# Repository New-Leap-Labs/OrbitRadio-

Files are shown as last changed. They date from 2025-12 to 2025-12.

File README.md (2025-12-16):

# Somaiya OrbitRadio

## APRS/AFSK Transceiver System

**STM32F4-based APRS packet radio system with Bell 202 AFSK modulation for amateur radio communication**

---

## Overview

This project implements a complete APRS (Automatic Packet Reporting System) transceiver using STM32F4 microcontroller with the following capabilities:

- Bell 202 AFSK modulation (1200 Hz mark, 2200 Hz space at 1200 baud)
- AX.25 packet protocol for amateur radio
- DRA818U radio module integration
- 4-bit R-2R DAC for audio generation
- UART packet reception with validation
- IWDG watchdog for system reliability

### Key Features

- Packet-triggered transmission (no auto-beacon)
- Robust input validation (ASCII-only payloads)
- Memory-optimized design (512-byte buffers)
- Watchdog protection against system hangs
- 9600 Hz sample rate audio generation
- Hardware-accelerated DAC output

---

## Hardware Requirements

### Microcontroller
- STM32F446RE Nucleo board (or compatible STM32F4 series)
- Upto 180 MHz system clock
- 512 KB Flash memory
- 128 KB SRAM + 4 KB backup SRAM

### Radio Module
- DRA818U/V UHF/VHF transceiver module
- Currently configured for UHF operation at 435.2480 MHz (default) or 435.2500 MHz (backup)
- Supports VHF operation as well (configurable when required)
- UART control interface at 9600 baud

### DAC Configuration (4-bit R-2R Ladder)

| STM32 Pin | DAC Bit | Resistor Value |
|---|---|---|
| PA6 | MSB (bit 0) | R |
| PA4 | bit 1 | 2R |
| PA1 | bit 2 | 4R |
| PA0 | LSB (bit 3) | 6R |

**R-2R Network:** Use 1kΩ for R, 2kΩ for 2R  
**Output:** Connect DAC output to DRA818 microphone input via 10µF coupling capacitor

### Pin Configuration

- PA10 (USART1 RX): Packet data input at 115200 baud
- PC7 (PTT_UHF): Push-to-talk control for DRA818
- PA5 (LD2): Status LED (toggles on valid packet reception)

---

## Packet Structure

### DataPacket_t Format (260 bytes total)

```c
typedef struct {
    uint8_t command_type;      // 0x01 = Frequency Change, 0x02 = Telemetry
    uint8_t payload_length;    // 1-256 bytes
    uint8_t padding[2];        // Reserved (ignored)
    uint8_t payload[256];      // ASCII text payload
} DataPacket_t;
```

### Valid Command Types

- 0x01 - Frequency change command (currently triggers telemetry)
- 0x02 - Telemetry transmission

### Payload Validation Rules

**Accepted Characters:**
- Printable ASCII: 0x20-0x7E (space through tilde)
- Whitespace: \t (0x09), \n (0x0A), \r (0x0D)

**Rejected Packets:**
- Empty payloads (length = 0)
- Oversized payloads (length > 256)
- Invalid command types (not 0x01 or 0x02)
- Non-ASCII data (binary/control characters)

---

## APRS Packet Format

Generated APRS packets follow AX.25 UI-frame structure:

```
Flag | Dest Addr | Src Addr | Path | Control | PID | Info Field | FCS | Flag
0x7E | VU2CWN-0  | VU3CDI-5 | WIDE1-1,WIDE2-1 | 0x03 | 0xF0 | >Payload... | CRC | 0x7E
```

### Callsign Configuration

Edit the following definitions in `main.c`:

```c
#define SRC_CALL   "VU3CDI"    // Source callsign
#define SRC_SSID   5           // Source SSID
#define DST_CALL   "VU2CWN"    // Destination callsign
#define DST_SSID   0           // Destination SSID
#define PATH1_CALL "WIDE1"     // Digipeater path 1
#define PATH1_SSID 1
#define PATH2_CALL "WIDE2"     // Digipeater path 2
#define PATH2_SSID 1
```

---

## Getting Started

### 1. Clone Repository

```bash
git clone https://github.com/yourusername/OrbitRadio-APRS.git
cd OrbitRadio-APRS
```

### 2. Open in STM32CubeIDE

- Open STM32CubeIDE
- Navigate to File → Open Projects from File System
- Select the project folder
- Build the project (Ctrl+B)

### 3. Configure IWDG Watchdog

- Open `RX_Final.ioc`
- Navigate to Computing → IWDG
- Enable IWDG
- Set Prescaler: 64, Reload: 4095 (timeout approximately 8.2 seconds)
- Save and regenerate code

### 4. Flash to STM32

- Connect STM32 Nucleo via USB
- Click Run (green play button) or press F11

### 5. Hardware Connections

```
STM32 PA10 (RX) ←─── UART TX from sender device
STM32 PC7 (PTT) ───→ DRA818 PTT pin
STM32 DAC Out   ───→ DRA818 MIC (via 10µF capacitor)
DRA818 Audio    ───→ Radio antenna/speaker
```

---

## Usage

### Sending a Packet (Python Example)

```python
import serial
import struct

ser = serial.Serial('COM3', 115200)  # Adjust port

# Create packet
command_type = 0x02  # Telemetry
payload = b"Temperature: 25.3C, Humidity: 60%"
payload_length = len(payload)

# Pack packet (4-byte header + payload)
packet = struct.pack('<BB2s', command_type, payload_length, b'\x00\x00')
packet += payload.ljust(256, b'\x00')  # Pad to 256 bytes

# Send
ser.write(packet)
print(f"Sent {len(packet)} bytes")
ser.close()
```

### Expected System Behavior

1. PTT activates (PC7 goes HIGH)
2. AFSK tones generated via DAC (1200/2200 Hz)
3. Radio transmits APRS packet
4. PTT releases after transmission

### Transmission Time Calculation

```
Time (seconds) = (Packet bytes × 8 bits) / 1200 baud
Example: 75 bytes = (75 × 8) / 1200 = 0.5 seconds
```

---

## AFSK Technical Details

### Bell 202 Standard

- Mark (binary 1): 1200 Hz
- Space (binary 0): 2200 Hz
- Baud rate: 1200 baud
- Sample rate: 9600 Hz (Timer3 interrupt)

### Audio Generation Pipeline

```
AX.25 Encoder → AFSK Modulator → Timer3 ISR → 4-bit DAC → Analog Audio
   (ax25.c)       (afsk.c)      (9600 Hz)    (R-2R)      (DRA818)
```

### Timer3 Configuration

```c
Clock: 84 MHz APB1
Prescaler: 83  → 84MHz / 84 = 1 MHz
Period: 103    → 1MHz / 104 ≈ 9615 Hz ≈ 9600 Hz
```

At 9600 Hz sample rate:
- 1200 Hz tone = 8 samples per cycle
- 2200 Hz tone = 4.36 samples per cycle

---

## Watchdog Protection

### IWDG Configuration

- Timeout: approximately 8.2 seconds
- Prescaler: 64
- Reload value: 4095
- LSI Clock: 32 kHz

### Refresh Points

- Main loop: Every 10ms
- Packet processing start
- During AFSK transmission (multiple points)
- After long delays

**Purpose:** Automatically reset system if hang or crash occurs

---

## Memory Usage

| Resource | Size | Usage |
| --- | --- | --- |
| Flash | 512 KB | Program code and constants |
| **SRAM** | **128 KB** | Runtime data, stack, heap |
| **Backup SRAM** | **4 KB** | Retained data during standby |
| AX.25 Buffer | 512 bytes  | Packet encoding |
| RX Buffer | 260 bytes  | UART reception |
| Process Buffer  | 260 bytes  | Packet processing |
| DAC Masks | 128 bytes  | Precomputed GPIO values |

### Optimizations

- Reduced AX.25 buffer from 4096 to 512 bytes
- Minimized stack usage in string operations
- Precomputed DAC lookup tables

---

## Troubleshooting

### Packets Rejected

**Causes:**
- Invalid command type (must be 0x01 or 0x02)
- Payload contains non-ASCII characters
- Payload length = 0 or > 256
- UART framing errors

**Solution:** Verify packet structure and ensure clean ASCII text

### No Audio Output

**Symptoms:** PTT activates but no tones  
**Causes:**
- R-2R DAC not connected properly
- Wrong GPIO pins
- Timer3 not running

**Solution:** Verify DAC wiring and check Timer3 initialization

### Radio Not Transmitting

**Symptoms:** Audio plays but no RF output  
**Causes:**
- DRA818 not initialized
- Wrong frequency/configuration
- PTT not connected

**Solution:** Check USART6 connection to DRA818 and verify AT commands

### System Hangs or Resets

**Symptoms:** Unexpected resets  
**Causes:**
- Watchdog timeout (hung code)
- Missing HAL_IWDG_Refresh() calls

**Solution:** Increase IWDG timeout or add more refresh points

---

## Project Structure

```
RX_Final/
├── Core/
│   ├── Inc/
│   │   ├── main.h              # Pin definitions, function prototypes
│   │   ├── afsk.h              # AFSK generator declarations
│   │   ├── ax25.h              # AX.25 encoder declarations
│   │   └── stm32f4xx_it.h      # Interrupt handlers
│   └── Src/
│       ├── main.c              # Main application logic
│       ├── afsk.c              # AFSK audio generation
│       ├── ax25.c              # AX.25 packet encoding
│       ├── stm32f4xx_it.c      # ISR implementations
│       └── stm32f4xx_hal_msp.c # HAL initialization
├── Drivers/                     # STM32 HAL drivers
├── RX_Final.ioc                # STM32CubeMX configuration
└── README.md                   # This file
```

---

## Technical References

- [APRS Protocol Specification](http://www.aprs.org/doc/APRS101.PDF)
- [AX.25 Link Access Protocol](https://www.tapr.org/pdf/AX25.2.2.pdf)
- [Bell 202 Standard](https://en.wikipedia.org/wiki/Bell_202_modem)
- [DRA818 Datasheet](http://www.dorji.com/docs/data/DRA818U.pdf)
- [STM32F4 Reference Manual](https://www.st.com/resource/en/reference_manual/dm00031020.pdf)

---

## Authors

**Somaiya OrbitRadio Team**

Callsigns: VU3CDI, VU3LTQ, VU3DNW, VU3DUN, VU2CWN

Project: APRS/AFSK Transceiver for Amateur Radio

---

## Acknowledgments

- STMicroelectronics for STM32Cube HAL
- APRS/AX.25 protocol developers
- DRA818 module creators
- Amateur radio community

---

## Contact

For questions or support:
- Open an issue on GitHub
- Email: nli@somaiya.edu

---

**73 de Somaiya OrbitRadio Team**

*Last updated: December 2025*

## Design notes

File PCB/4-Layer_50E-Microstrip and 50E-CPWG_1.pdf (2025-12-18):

StackName: 2-Layer | Version: | Revision: | Modification: | Date of Revision: | Editor | Page 2/2
Date: 11-02-2023 | Associated Documents:
Author:
Department:
Site:

www.polarinstruments.com

| Screened Ident | | | | Ident
Liquid PhotoImageable Mask | 0.984 | SolderMask 4.000
1 | Copper Foil | 1, 2 | 1.378 | 1.378 | Copper
FR4 | 3.307 | 3.307 | 4.300
FR4 | 2.717 | 2.717 | 4.300
2 | | | 1.378 | 1.378
FR4 | 47.244 | 47.244 | 4.300
3 | | | 1.378 | 1.378
FR4 | 2.717 | 2.717 | 4.300
FR4 | 3.307 | 3.307 | 4.300
4 | Copper Foil | 3 | 1.378 | 1.378 | Copper
Liquid PhotoImageable Mask | 0.984 | SolderMask 4.000
| Screened Ident | | | | Ident

64.8031

1 | Coated Microstrip 1B | 1 | 2 | 0 | 9.700 | 0.000 | 0.000 | 50.000 | 49.940 | 10.000
2 | Coated Coplanar Strips With Lower Ground 1B | 1 | 2 | 0 | 8.800 | 0.000 | 9.000 | 50.000 | 50.360 | 10.000
3 | Coated Microstrip 1B | 4 | 3 | 0 | 9.700 | 0.000 | 0.000 | 50.000 | 49.940 | 10.000

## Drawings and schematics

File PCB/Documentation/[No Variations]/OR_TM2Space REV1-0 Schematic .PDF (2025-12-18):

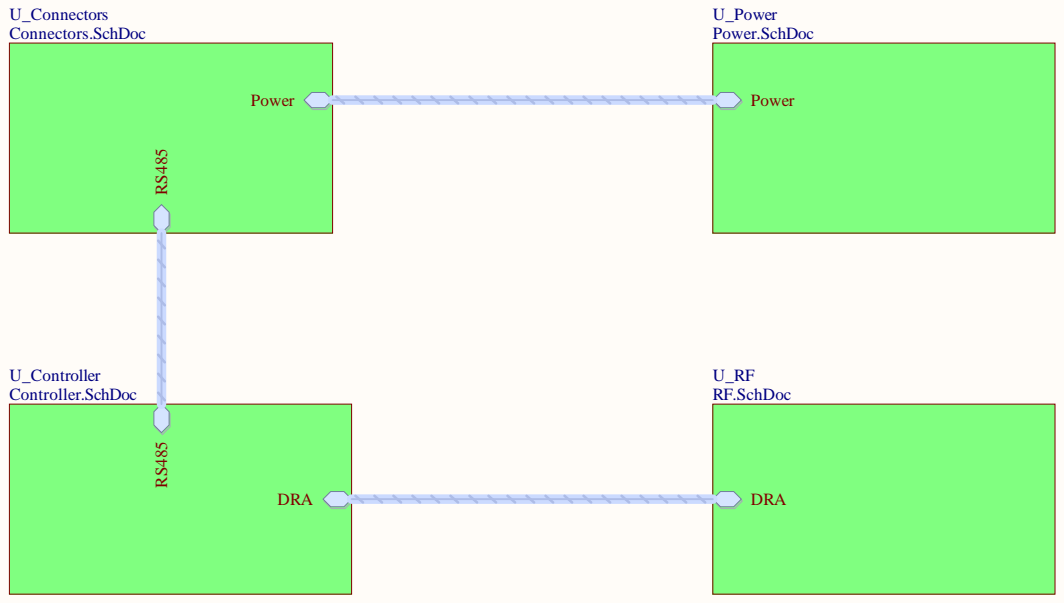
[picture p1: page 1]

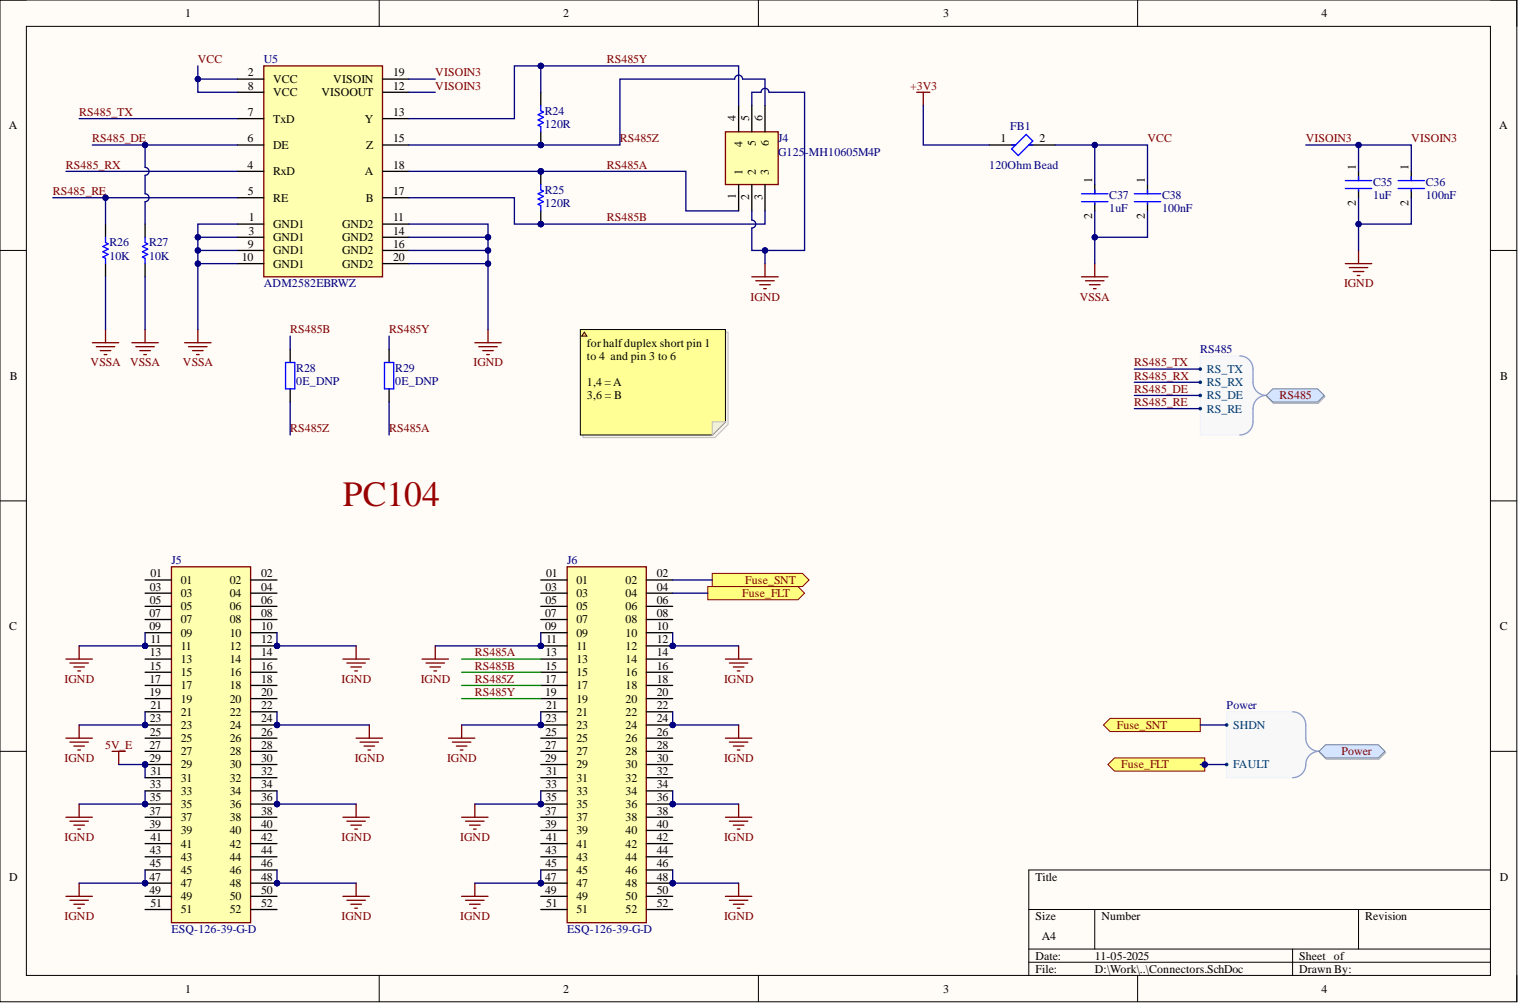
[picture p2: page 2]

for half duplex short pin 1
to 4 and pin 3 to 6

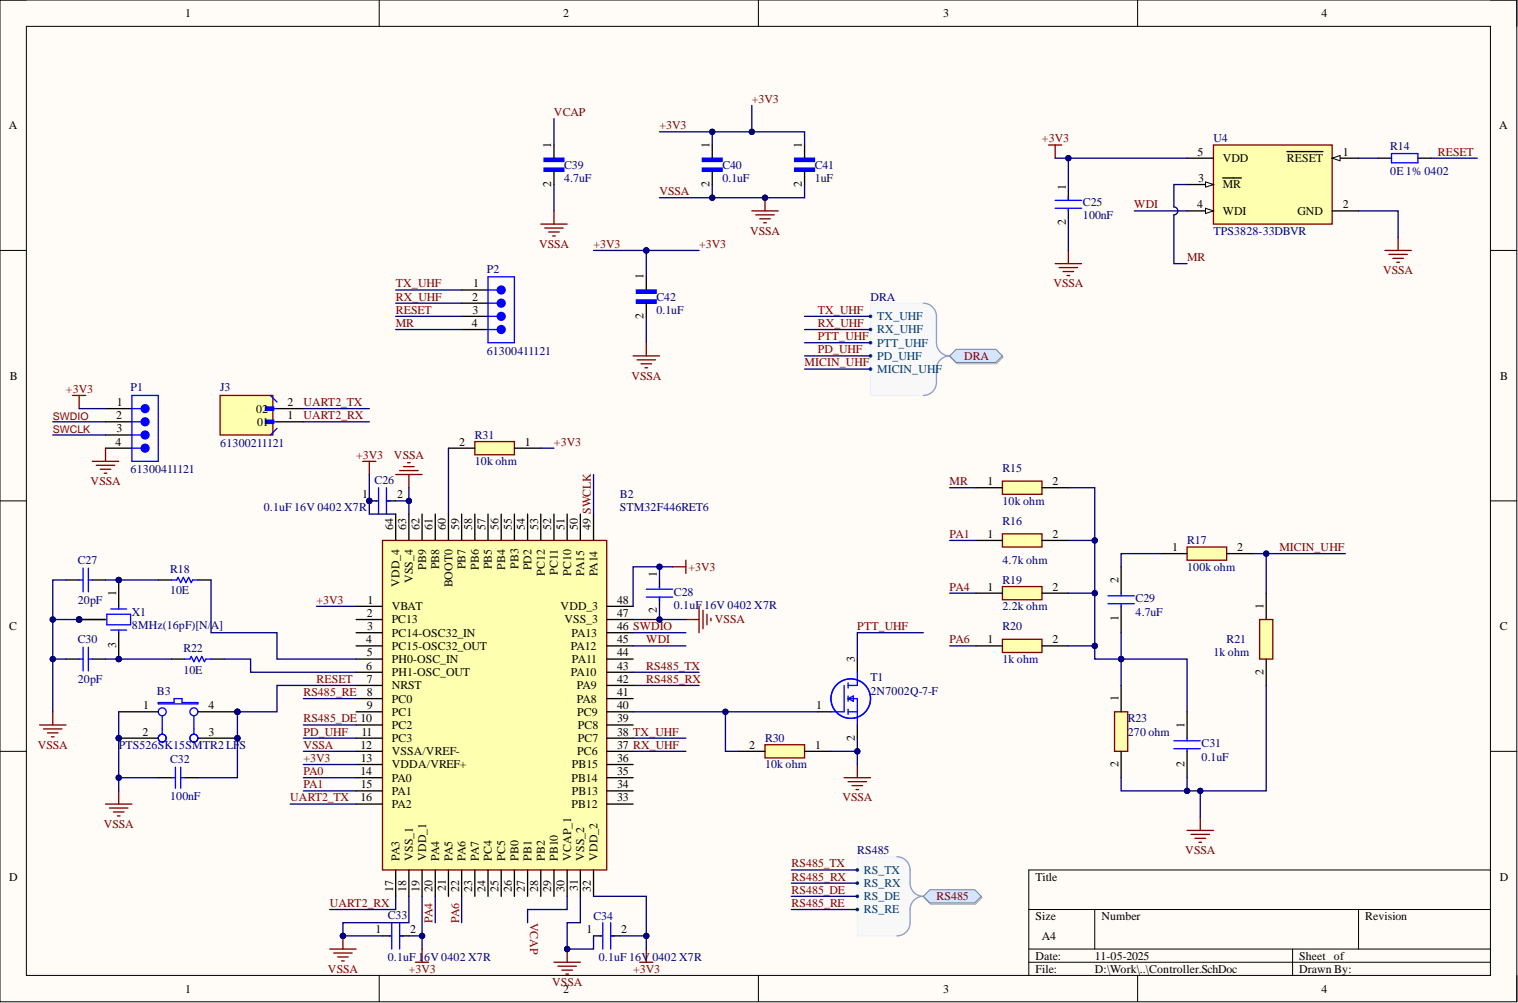
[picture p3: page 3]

PC14-OSC32_IN 3 | SWDIO
PC15-OSC32_OUT 4 | WDI
PH0-OSC_IN 5 | RS485_TX

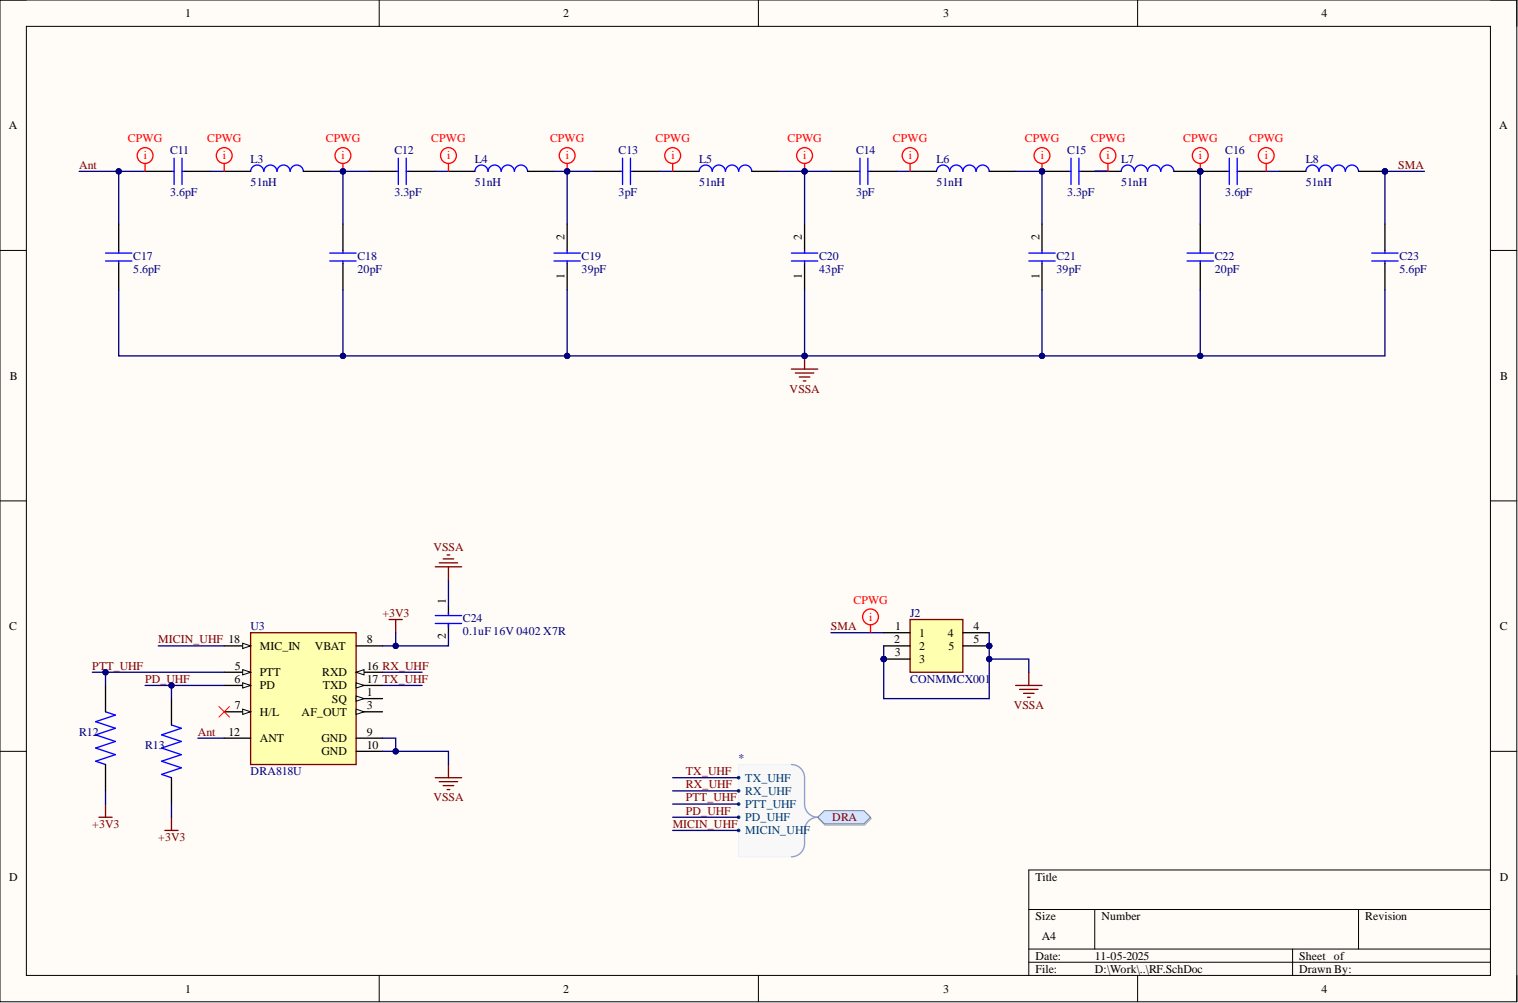
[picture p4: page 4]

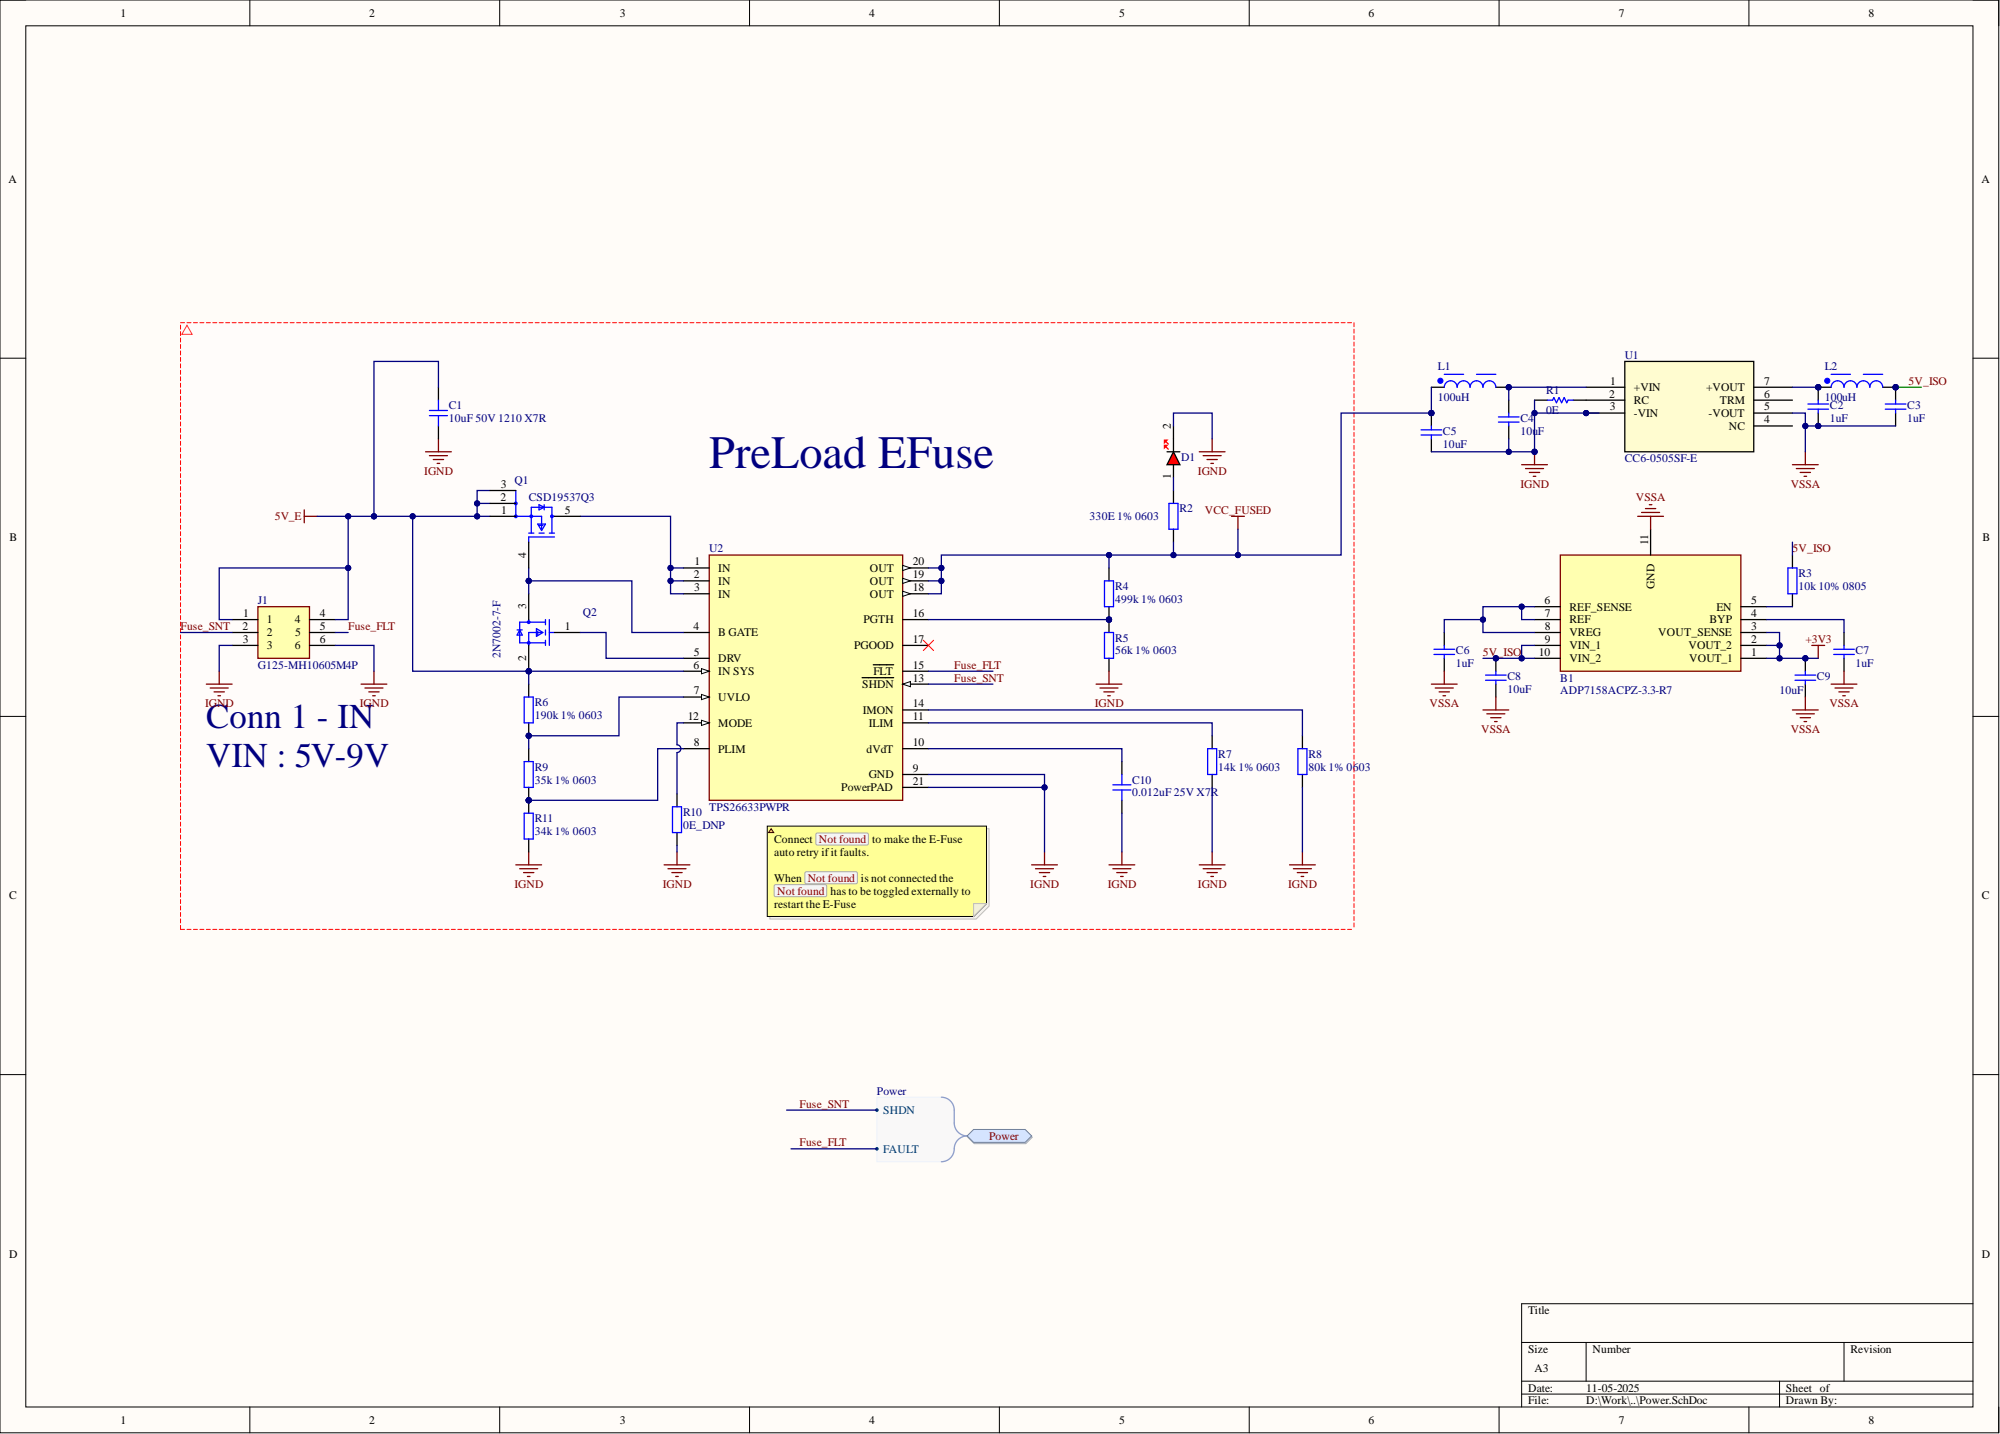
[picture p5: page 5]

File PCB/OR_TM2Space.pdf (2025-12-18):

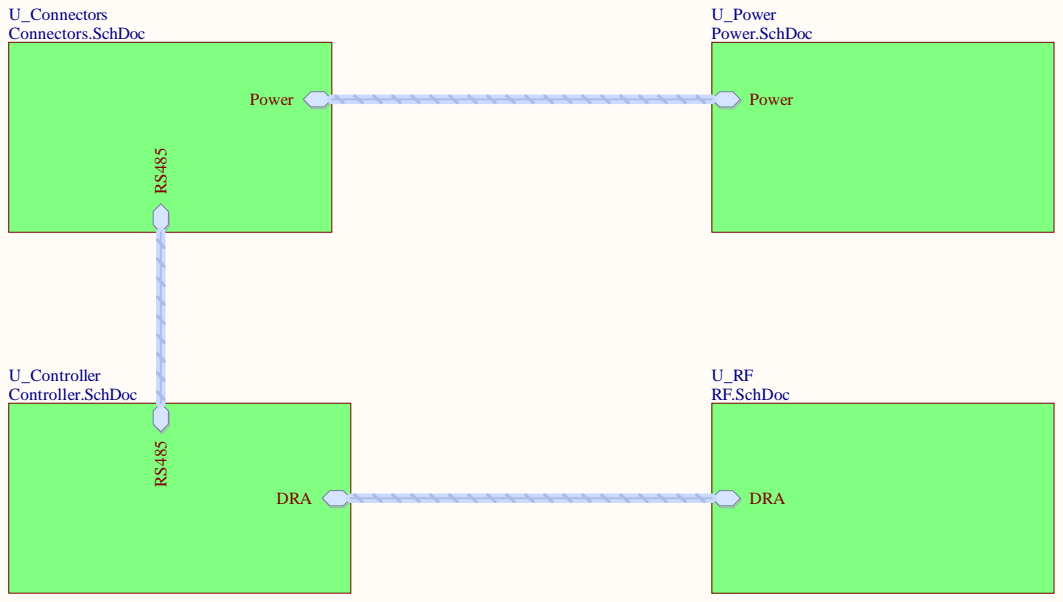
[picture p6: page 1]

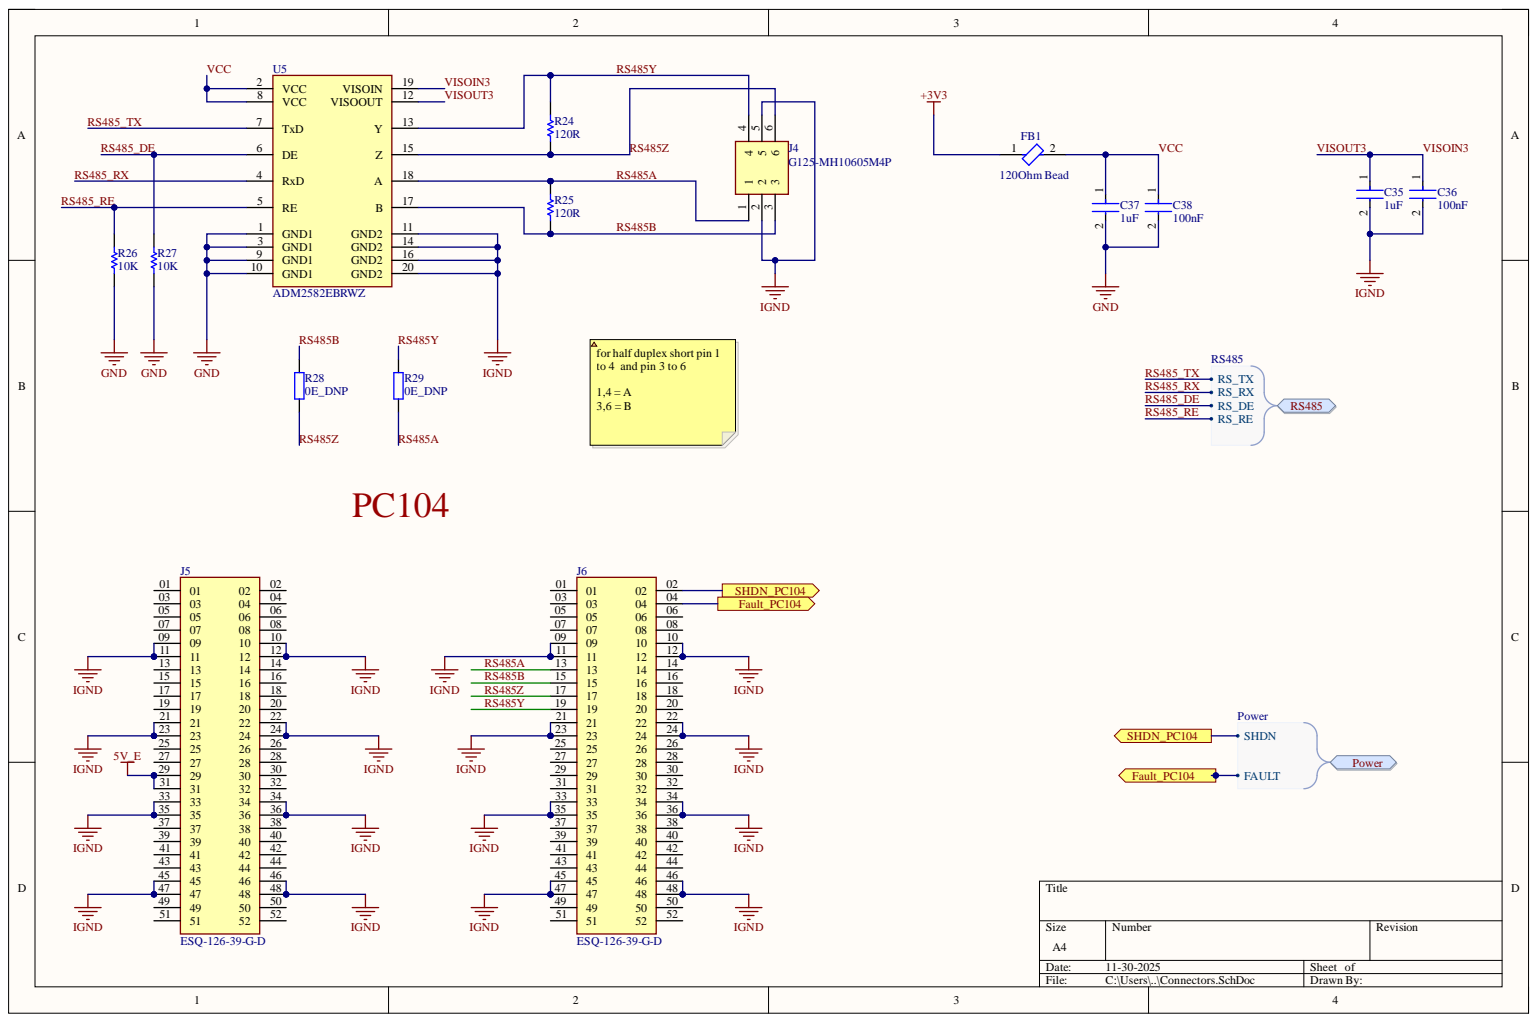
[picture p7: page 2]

DE 6 RxD 4 RE 5 GND1 1

for half duplex short pin 1
to 4 and pin 3 to 6

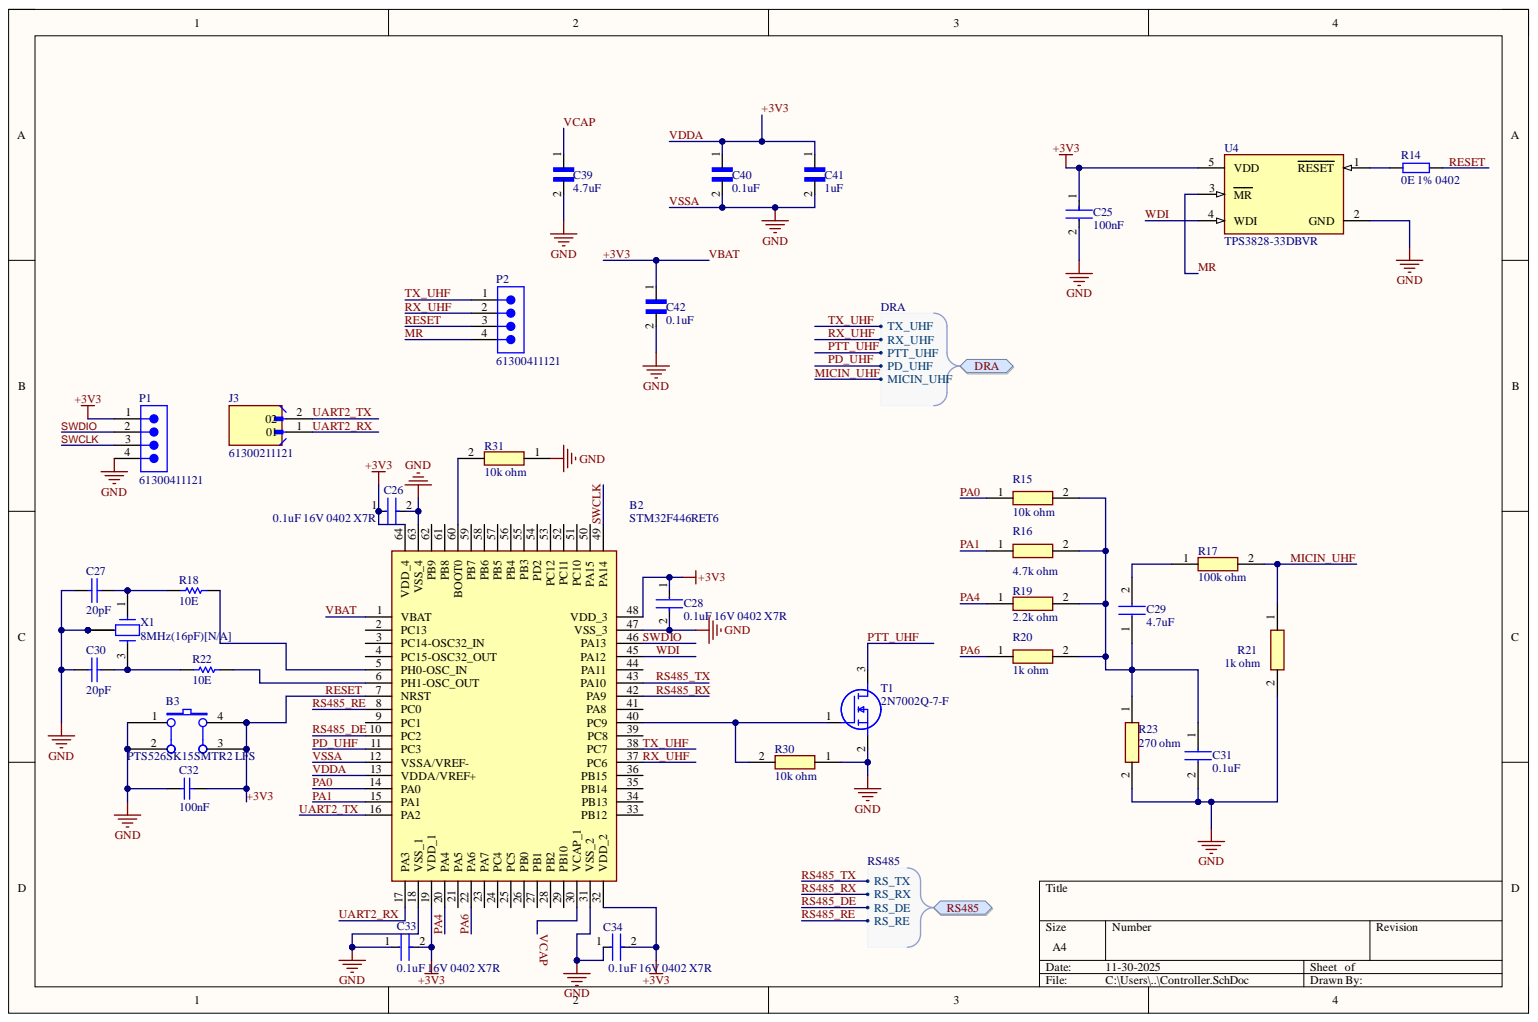
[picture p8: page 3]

PC14-OSC32_IN 3 | SWDIO
PC15-OSC32_OUT 4 | WDI
PH0-OSC_IN 5 | RS485_TX

UART2_RX | | C34

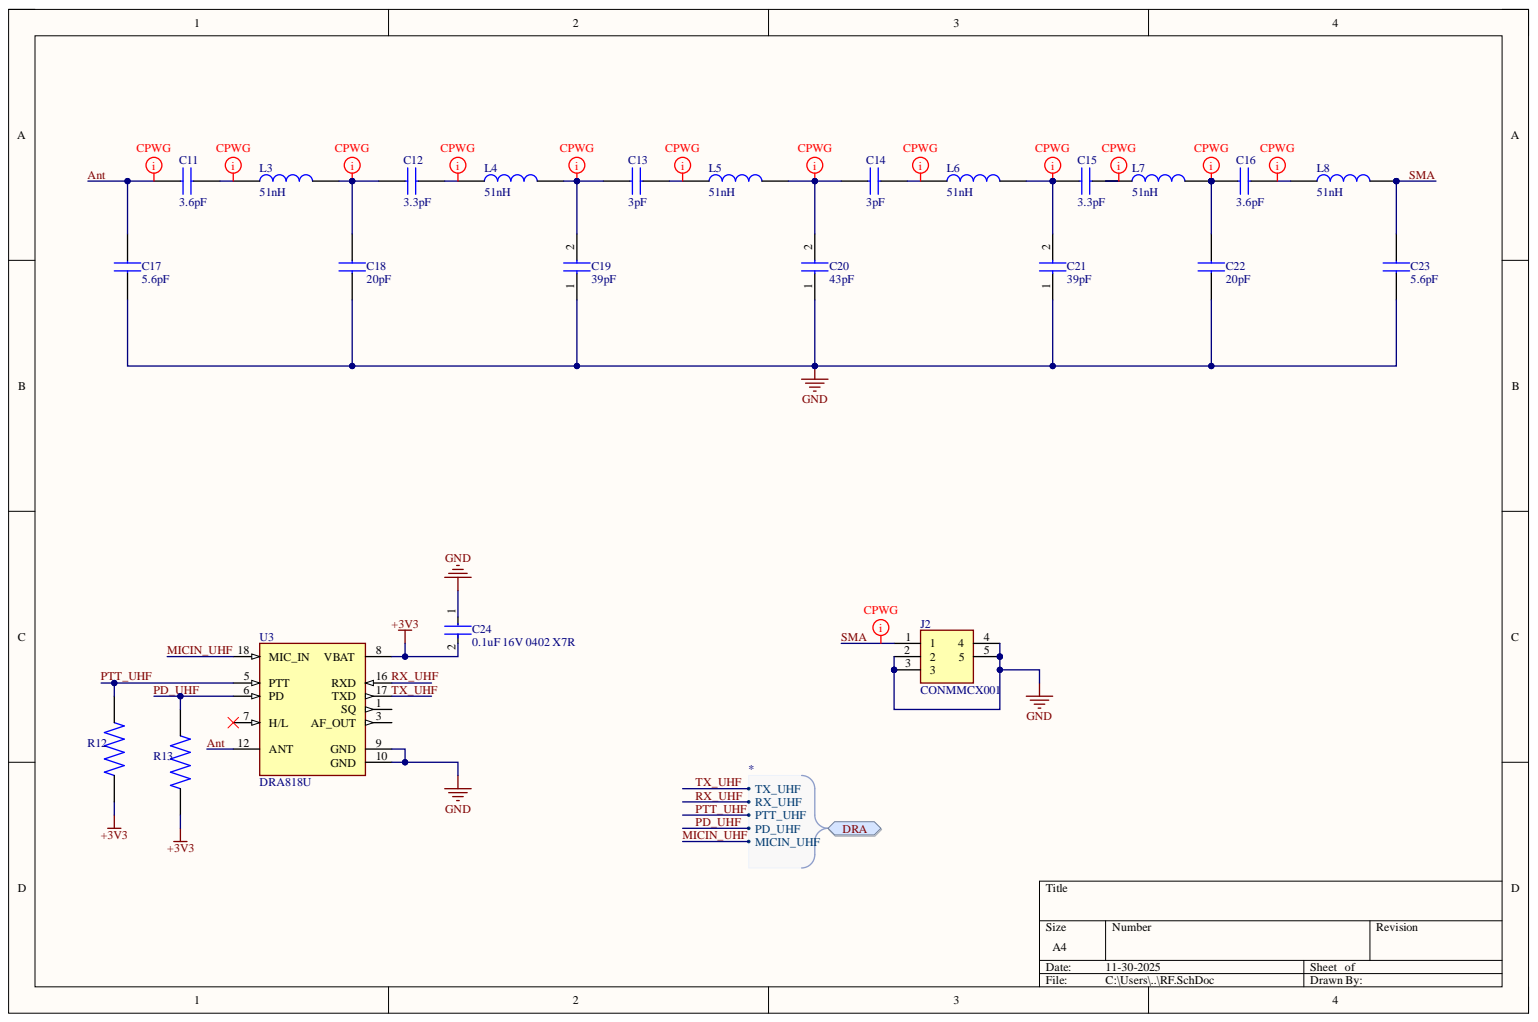
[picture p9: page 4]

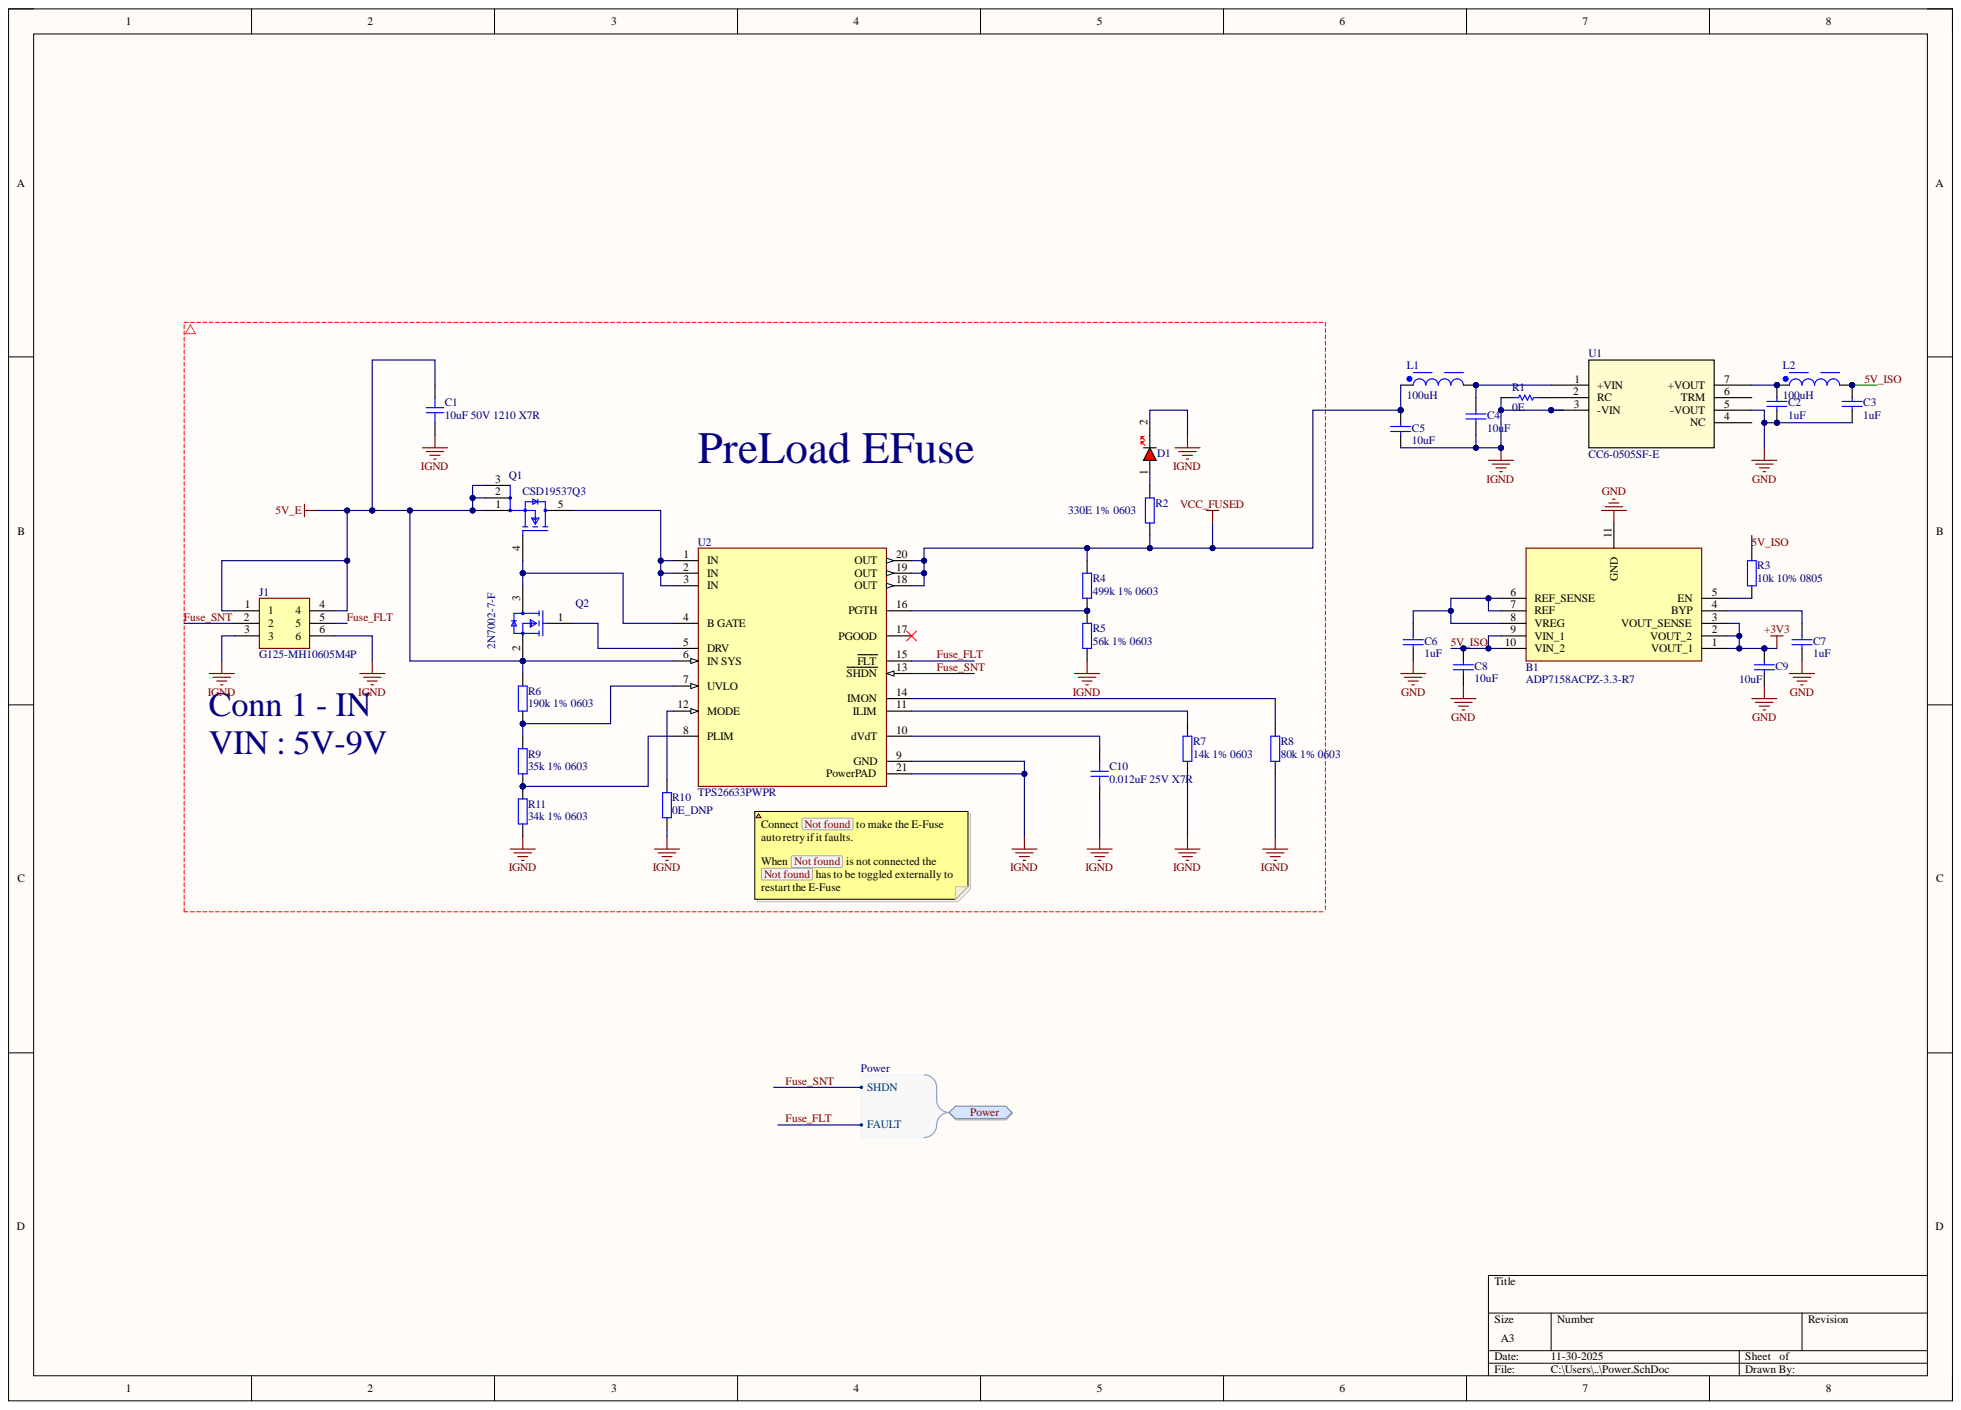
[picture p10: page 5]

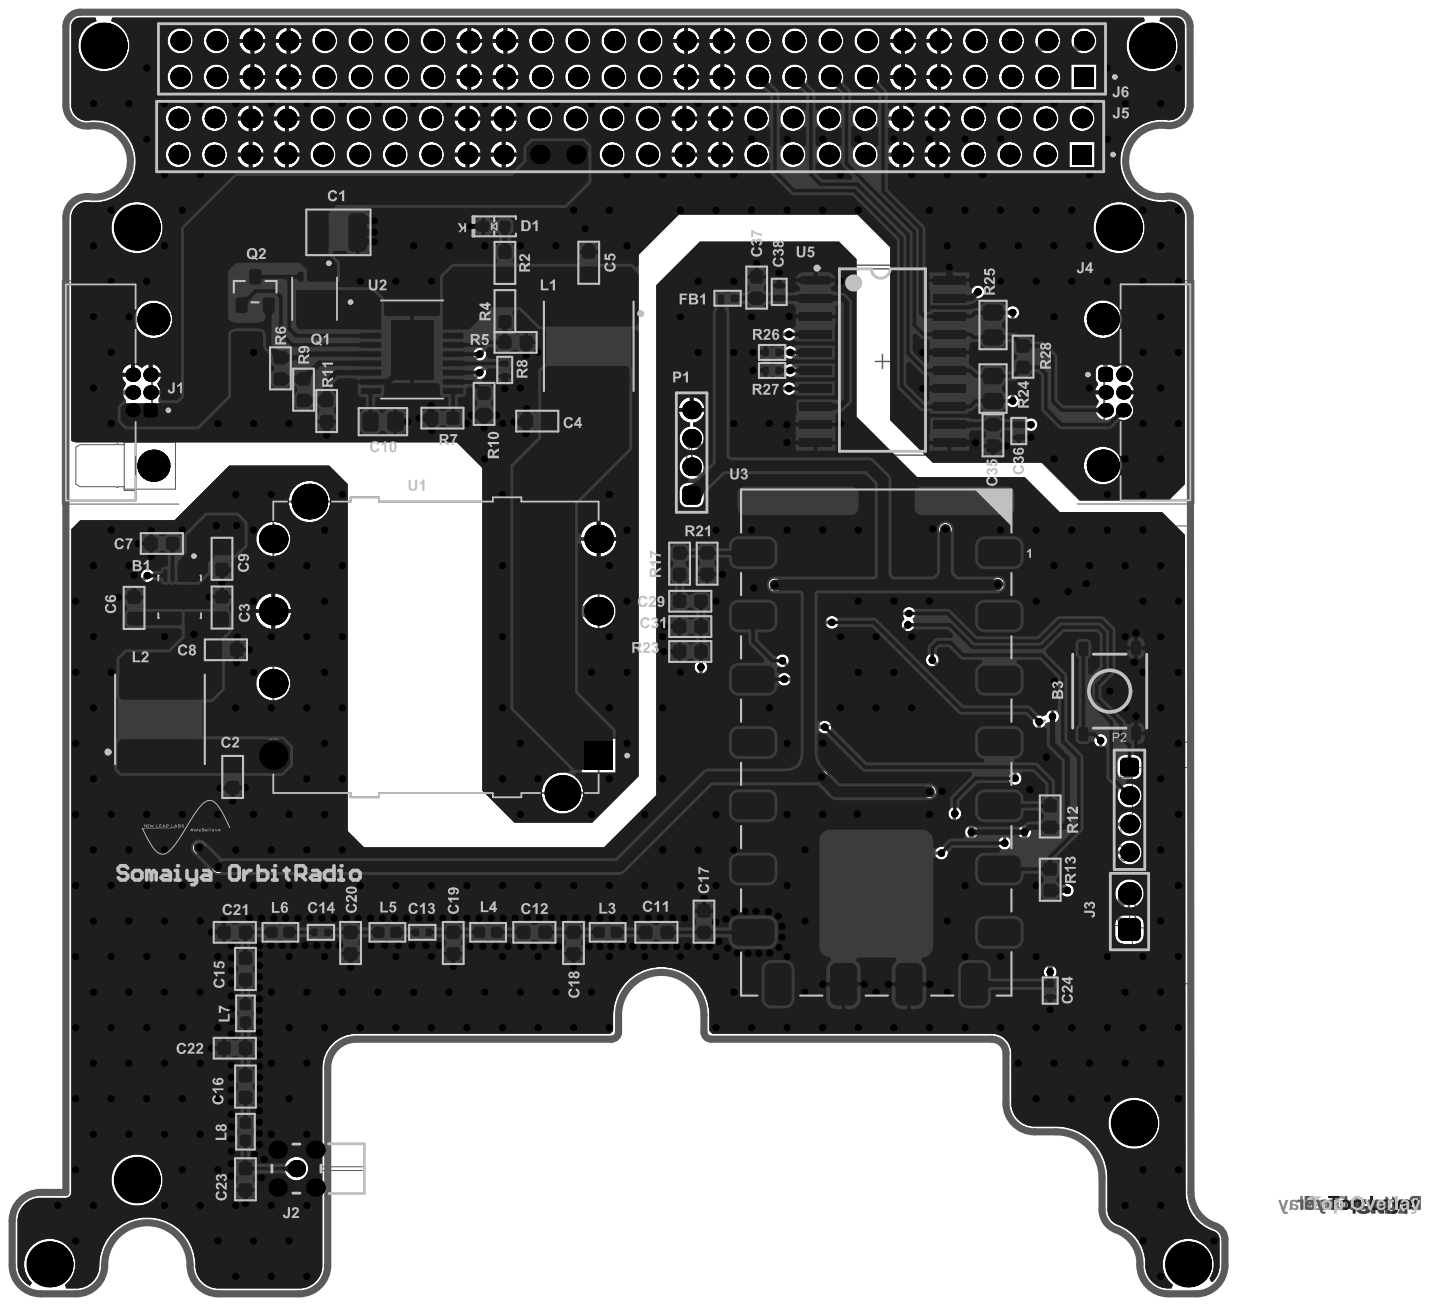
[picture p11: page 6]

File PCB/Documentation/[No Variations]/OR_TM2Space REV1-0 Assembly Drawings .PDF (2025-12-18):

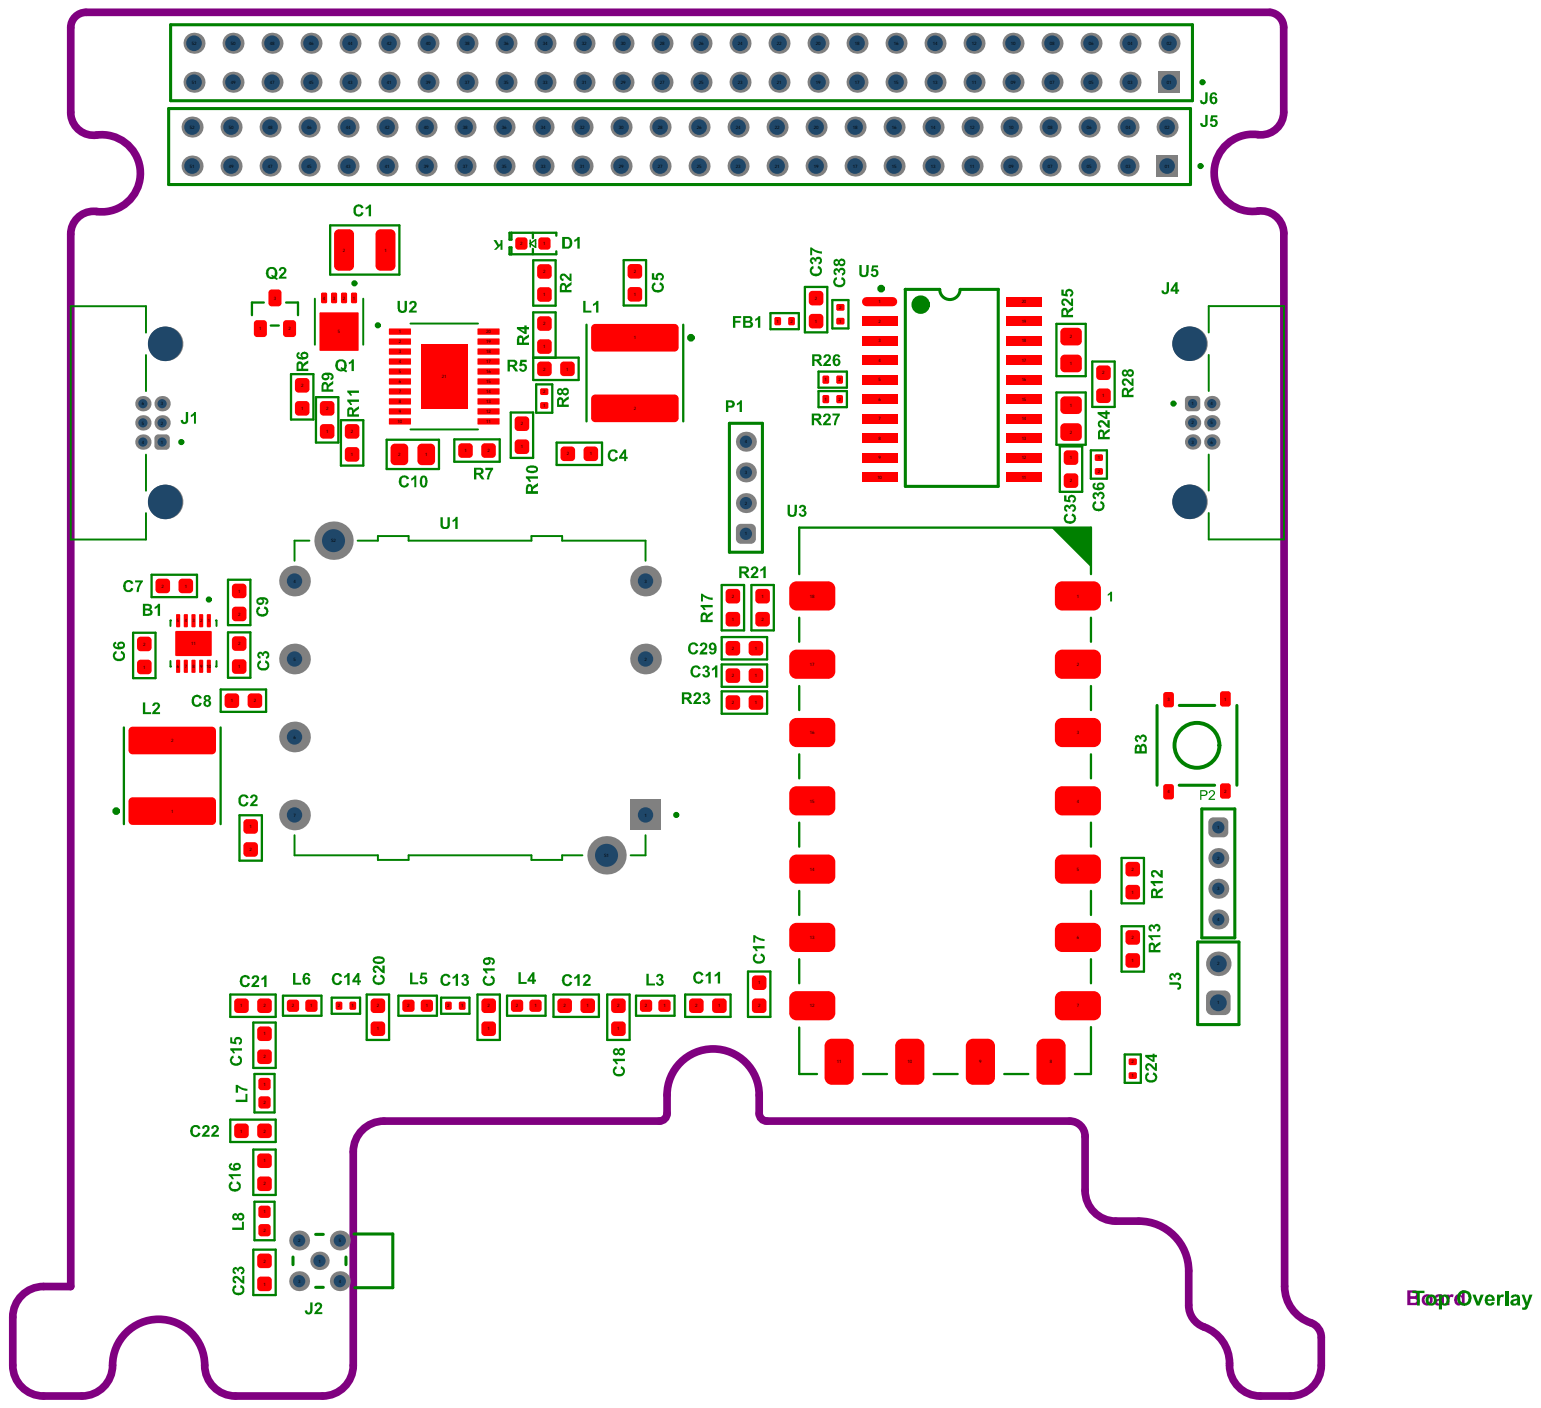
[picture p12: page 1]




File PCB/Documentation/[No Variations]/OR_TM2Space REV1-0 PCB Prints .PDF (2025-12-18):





13 13 13 | | | 1 2 1 2 1 2
14 14 14 15 15 15 | 1 1 1 | 1 1 1

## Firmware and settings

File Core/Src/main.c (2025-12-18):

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
/* Includes ------------------------------------------------------------------*/
#include "main.h"

/* USER CODE BEGIN Includes */
#include "afsk.h"
#include "ax25.h"
#include <string.h>
#include <stdint.h>

/* USER CODE END Includes */

/* USER CODE BEGIN PD */
#define CMD_TYPE_FREQ_CHANGE  0x01
#define CMD_TYPE_TELEMETRY    0x02

/* USER CODE END PD */

/* USER CODE BEGIN PM */
#define PKT_MAX_PAYLOAD     256
#define PKT_HEADER_SIZE     4
#define PKT_TOTAL_SIZE      260

/* USER CODE END PM */

TIM_HandleTypeDef htim3;

UART_HandleTypeDef huart1;
UART_HandleTypeDef huart2;
UART_HandleTypeDef huart6;

IWDG_HandleTypeDef hiwdg;

/* USER CODE BEGIN PV */
static const char SRC_CALL[]  = "VU3CDI";
static const uint8_t SRC_SSID = 5;
static const char DST_CALL[]  = "VU2CWN";
static const uint8_t DST_SSID = 0;
static const char PATH1_CALL[] = "WIDE";
static const uint8_t PATH1_SSID = 1;
static const char PATH2_CALL[] = "WIDE";
static const uint8_t PATH2_SSID = 2;

/* Frequency control */
#define FREQ_DEFAULT "435.2480"
#define FREQ_BACKUP  "435.2500"
static volatile uint8_t use_backup_freq = 0;

/* Packet structure */
typedef struct __attribute__((packed)) {
    uint8_t command_type;
    uint8_t payload_length;
    uint8_t padding[2];
    uint8_t payload[PKT_MAX_PAYLOAD];
} DataPacket_t;

/* Reception buffer - receives complete packet structure */
static DataPacket_t rxData;
static DataPacket_t processData;
static volatile uint8_t packet_ready = 0;

/* Statistics */
static uint32_t packets_valid = 0;
static uint32_t packets_rejected = 0;
static uint32_t uart_errors = 0;

/* Buffers - Reduced size for memory optimization */
#define AX25_BUF_SIZE 512  // Reduced from 4096
static uint8_t ax25_buffer[AX25_BUF_SIZE];
static uint16_t ax25_len = 0;

/* DAC pin masks for 4-bit R-2R ladder DAC */
static uint32_t dac_set_masks[16];
static uint32_t dac_reset_masks[16];

/* USER CODE END PV */

void SystemClock_Config(void);
static void MX_GPIO_Init(void);
static void MX_USART2_UART_Init(void);
static void MX_USART1_UART_Init(void);
static void MX_USART6_UART_Init(void);
static void MX_TIM3_Init(void);
static void MX_IWDG_Init(void);
/* USER CODE BEGIN PFP */
static void DRA_Send(const char *s);
static void DRA_Init(void);
static void ProcessCommand(DataPacket_t *pkt);
static void TransmitTelemetry(const char *payload_text);
static inline int IsValidPacket(DataPacket_t *packet);
extern uint8_t afsk_isBusy(void);
/* USER CODE END PFP */

/* USER CODE BEGIN 0 */

/**
 * @brief APRS/AFSK Audio Tone Generation Overview
 *
 * This code implements Bell 202 AFSK (Audio Frequency Shift Keying) for APRS:
 * - Mark (1):  1200 Hz
 * - Space (0): 2200 Hz
 * - Baud rate: 1200 baud
 *
 * Signal Flow:
 * 1. AX.25 frame encoding (ax25_encode) - Creates proper APRS packet
 * 2. AFSK generation (afsk_generate) - Converts bits to audio samples
 * 3. Timer interrupt (afsk_timer_tick) - Outputs samples at 9600 Hz via DAC
 * 4. DAC output (DAC_Write4) - 4-bit R-2R ladder creates analog audio
 * 5. Audio feeds DRA818U microphone input
 *
 * Timer3 Configuration for 9600 Hz:
 * - System clock: 84 MHz (APB1)
 * - Prescaler: 83 (84MHz / 84 = 1 MHz)
 * - Period: 103 (1MHz / 104 ≈ 9615 Hz ≈ 9600 Hz)
 *
 * At 9600 Hz sample rate:
 * - 1200 Hz tone = 8 samples per cycle (9600/1200)
 * - 2200 Hz tone = 4.36 samples per cycle (9600/2200)
 */

/* Check if payload contains printable ASCII */
static uint8_t IsValidPayload(const uint8_t *payload, uint8_t len)
{
    if (len == 0 || len > 256) return 0;

    for (uint8_t i = 0; i < len; i++) {
        if ((payload[i] >= 32 && payload[i] <= 126) ||
            payload[i] == '\r' || payload[i] == '\n' || payload[i] == '\t') {
            continue;
        }
        return 0;
    }
    return 1;
}

/* Validation function - CHECK COMMAND TYPE FIRST */
static inline int IsValidPacket(DataPacket_t *packet)
{
    if (packet->command_type < CMD_TYPE_FREQ_CHANGE ||
        packet->command_type > CMD_TYPE_TELEMETRY) {
        return 0;
    }

    if (packet->payload_length == 0 || packet->payload_length > 256) {
        return 0;
    }

    if (!IsValidPayload(packet->payload, packet->payload_length)) {
        return 0;
    }

    return 1;
}

/**
 * @brief Write 4-bit value to R-2R DAC
 * @param v: 4-bit value (0-15)
 *
 * DAC Pin Assignment:
 * - LSB (bit 0): PA4
 * - BIT_1 (bit 1): PA6
 * - BIT_2 (bit 2): PA7
 * - MSB (bit 3): PA0
 *
 * Uses precomputed masks for fast GPIO writes via BSRR register
 */
void DAC_Write4(uint8_t v)
{
    GPIOA->BSRR = dac_set_masks[v & 0x0F] | dac_reset_masks[v & 0x0F];
}

/**
 * @brief Precompute GPIO masks for all 16 DAC values
 *
 * BSRR register layout:
 * - Lower 16 bits: Set pins (write 1)
 * - Upper 16 bits: Reset pins (write 1)
 *
 * This optimization allows single-cycle GPIO writes
 */
void DAC_PrecomputeMasks(void)
{
    for (uint8_t v = 0; v < 16; v++) {
        uint32_t set_mask = 0;
        uint32_t reset_mask = 0;
        if (v & 0x01) set_mask |= LSB_Pin; else reset_mask |= (LSB_Pin << 16);
        if (v & 0x02) set_mask |= BIT_1_Pin; else reset_mask |= (BIT_1_Pin << 16);
        if (v & 0x04) set_mask |= BIT_2_Pin; else reset_mask |= (BIT_2_Pin << 16);
        if (v & 0x08) set_mask |= MSB_Pin; else reset_mask |= (MSB_Pin << 16);
        dac_set_masks[v] = set_mask;
        dac_reset_masks[v] = reset_mask;
    }
}

/**
 * @brief Timer3 interrupt callback - AFSK audio sample output
 *
 * Called at 9600 Hz to generate AFSK audio tones:
 * - afsk_timer_tick() fetches next audio sample
 * - Sample output via DAC_Write4()
 * - Creates 1200 Hz (mark) and 2200 Hz (space) tones
 *
 * At 9600 Hz sample rate:
 * - 1200 Hz: 8 samples per cycle
 * - 2200 Hz: ~4.36 samples per cycle
 */
void HAL_TIM_PeriodElapsedCallback(TIM_HandleTypeDef *htim)
{
    if (htim->Instance == TIM3) {
        afsk_timer_tick();
    }
}

/* UART Receive Complete Callback - Receives COMPLETE PACKET */
void HAL_UART_RxCpltCallback(UART_HandleTypeDef *huart)
{
    if (huart->Instance == USART1)
    {
        if (IsValidPacket(&rxData)) {
            packets_valid++;
            memcpy(&processData, &rxData, sizeof(DataPacket_t));
            packet_ready = 1;
            HAL_GPIO_TogglePin(LD2_GPIO_Port, LD2_Pin);
        } else {
            packets_rejected++;
        }

        HAL_UART_Receive_IT(&huart1, (uint8_t*)&rxData, sizeof(DataPacket_t));
    }
}

void HAL_UART_ErrorCallback(UART_HandleTypeDef *huart)
{
    if (huart->Instance == USART1)
    {
        __HAL_UART_CLEAR_OREFLAG(huart);
        __HAL_UART_CLEAR_NEFLAG(huart);
        __HAL_UART_CLEAR_FEFLAG(huart);
        __HAL_UART_CLEAR_PEFLAG(huart);

        uart_errors++;

        HAL_UART_Receive_IT(&huart1, (uint8_t*)&rxData, sizeof(DataPacket_t));
    }
}

/* Command Processing */
static void ProcessCommand(DataPacket_t *packet_cmd)
{
    HAL_IWDG_Refresh(&hiwdg);

    if (!IsValidPacket(packet_cmd)) {
        return;
    }

    if (packet_cmd->payload_length < PKT_MAX_PAYLOAD) {
        packet_cmd->payload[packet_cmd->payload_length] = '\0';
    } else {
        packet_cmd->payload[PKT_MAX_PAYLOAD - 1] = '\0';
    }

    switch (packet_cmd->command_type)
    {
        case CMD_TYPE_FREQ_CHANGE:
            TransmitTelemetry((char*)packet_cmd->payload);
            break;

        case CMD_TYPE_TELEMETRY:
            TransmitTelemetry((char*)packet_cmd->payload);
            break;

        default:
            break;
    }
}

/**
 * @brief Transmit APRS packet via AFSK
 *
 * APRS Packet Structure:
 * 1. Flag (0x7E) - Packet delimiter
 * 2. Destination Address (7 bytes) - VU2CWN-0
 * 3. Source Address (7 bytes) - VU3CDI-5
 * 4. Path (14 bytes) - WIDE1-1,WIDE2-1
 * 5. Control (0x03), PID (0xF0)
 * 6. Information Field - ">Hello World Somaiya OrbitRadio 73"
 * 7. FCS (2 bytes) - Frame Check Sequence (CRC)
 * 8. Flag (0x7E)
 *
 * The ax25_encode() function creates this properly formatted AX.25 frame
 * The afsk_generate() converts it to audio samples at 9600 Hz
 * Timer3 ISR outputs samples at 9600 Hz via DAC
 */
static void TransmitTelemetry(const char *payload_text)
{
    char temp[128];  // Reduced from 300
    uint8_t len = 0;

    // Manual string concatenation to save stack
    temp[len++] = '>';
    while (*payload_text && len < 100) {
        temp[len++] = *payload_text++;
    }
    const char *suffix = " | SVV-KJSIT x TakeMe2Space, NEW LEAP LABS, Somaiya OrbitRadio 73";
    while (*suffix && len < 127) {
        temp[len++] = *suffix++;
    }
    temp[len] = '\0';

    HAL_IWDG_Refresh(&hiwdg);

    memset(ax25_buffer, 0, AX25_BUF_SIZE);
    ax25_len = 0;

    ax25_encode(ax25_buffer, &ax25_len,
                SRC_CALL, SRC_SSID,
                DST_CALL, DST_SSID,
                PATH1_CALL, PATH1_SSID,
                PATH2_CALL, PATH2_SSID,
                temp);

    if (ax25_len == 0) {
        return;
    }

    HAL_Delay(200);
    HAL_IWDG_Refresh(&hiwdg);

    afsk_generate(ax25_buffer, ax25_len);

    HAL_GPIO_WritePin(PTT_UHF_GPIO_Port, PTT_UHF_Pin, GPIO_PIN_SET);
    HAL_Delay(1000);
    HAL_IWDG_Refresh(&hiwdg);

    afsk_start();

    uint32_t start = HAL_GetTick();
    while (afsk_isBusy() && (HAL_GetTick() - start) < 20000) {
        HAL_Delay(10);
        HAL_IWDG_Refresh(&hiwdg);
    }

    HAL_Delay(200);
    afsk_stop();

    HAL_GPIO_WritePin(PTT_UHF_GPIO_Port, PTT_UHF_Pin, GPIO_PIN_RESET);
    HAL_Delay(100);
}

void DRA_Send(const char *s)
{
    HAL_UART_Transmit(&huart6, (uint8_t*)s, strlen(s), HAL_MAX_DELAY);
    HAL_UART_Transmit(&huart6, (uint8_t*)"\r\n", 2, HAL_MAX_DELAY);
}

void DRA_Init(void)
{
    const char *freq = use_backup_freq ? FREQ_BACKUP : FREQ_DEFAULT;
    HAL_Delay(500);
    DRA_Send("AT+DMOCONNECT");
    HAL_Delay(300);

    char cmd[64];  // Reduced from 100
    uint8_t idx = 0;
    const char *prefix = "AT+DMOSETGROUP=0,";
    while (*prefix) cmd[idx++] = *prefix++;
    const char *f = freq;
    while (*f) cmd[idx++] = *f++;
    cmd[idx++] = ',';
    f = freq;
    while (*f) cmd[idx++] = *f++;
    const char *suffix = ",0000,0,0000";
    while (*suffix) cmd[idx++] = *suffix++;
    cmd[idx] = '\0';

    DRA_Send(cmd);
    HAL_Delay(300);
    DRA_Send("AT+DMOSETVOLUME=6");
    HAL_Delay(200);
}

/* USER CODE END 0 */

/**
  * @brief  The application entry point.
  * @retval int
  */
int main(void)
{

  /* MCU Configuration--------------------------------------------------------*/

  /* Reset of all peripherals, Initializes the Flash interface and the Systick. */
  HAL_Init();

  /* Configure the system clock */
  SystemClock_Config();

  /* Initialize all configured peripherals */
  MX_GPIO_Init();
  MX_USART2_UART_Init();
  MX_USART1_UART_Init();
  MX_USART6_UART_Init();
  MX_TIM3_Init();
  MX_IWDG_Init();
  /* USER CODE BEGIN 2 */
  DAC_PrecomputeMasks();
  HAL_Delay(100);

  afsk_Init();

  DRA_Init();

  memset(&rxData, 0, sizeof(DataPacket_t));
  memset(&processData, 0, sizeof(DataPacket_t));
  packet_ready = 0;

  HAL_UART_Receive_IT(&huart1, (uint8_t*)&rxData, sizeof(DataPacket_t));

  uint32_t last_status = HAL_GetTick();

  /* USER CODE END 2 */

  /* Infinite loop */
  /* USER CODE BEGIN WHILE */
  while (1)
  {
    HAL_IWDG_Refresh(&hiwdg);

    if (packet_ready)
    {
        packet_ready = 0;
        ProcessCommand(&processData);
    }

    uint32_t now = HAL_GetTick();

    if ((now - last_status) >= 10000) {
        last_status = now;
    }

    HAL_Delay(10);
    /* USER CODE END WHILE */

    /* USER CODE BEGIN 3 */
  }
  /* USER CODE END 3 */
}

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

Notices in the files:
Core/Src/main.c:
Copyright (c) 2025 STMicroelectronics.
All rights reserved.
